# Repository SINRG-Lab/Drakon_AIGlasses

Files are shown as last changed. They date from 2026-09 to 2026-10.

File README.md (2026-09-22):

# Drakon AI Glasses

Hardware, firmware, and 3D models for the Drakon AI smart glasses.

This repository is the single home for everything physical and embedded: board
designs, embedded firmware, and printable frame parts. Application code,
measurement studies, and companion apps live in other repositories.

## Editions

The glasses come in two open-source editions that share a frame and audio
pipeline but differ in how they reach the network.

| Edition | Directory | Connectivity | Status |
|---|---|---|---|
| Companion | [`companion/`](companion/) | Wi-Fi / BLE, relayed via a paired device | v3 fabricated, v4 in design |
| Standalone | [`standalone/`](standalone/) | On-board cellular | v1 in design |

## Versions

Each edition is numbered independently — `companion/v3` and `standalone/v1` are
unrelated designs. Numbering continues each edition's own history, so the
companion boards start at v3 to match the `pcbv3` the team already builds.

| Version | Status |
|---|---|
| [`companion/v3`](companion/v3/) | **Current** — left and right boards fabricated |
| [`companion/v4`](companion/v4/) | Next — in design, empty |
| [`standalone/v1`](standalone/v1/) | First board — in design, empty |

A new version directory is created when the PCB changes in a way that breaks
compatibility with existing firmware or frame parts. Small fixes land in the
existing version. See [`docs/versioning.md`](docs/versioning.md).

## Layout

Every build is **two PCBs**, one per temple, so `hardware/` splits left/right.

```
<edition>/<version>/
├── firmware/            Embedded source for that board version
│   ├── src/  include/  lib/
├── hardware/
│   ├── left/            Left temple board
│   │   ├── kicad/       The KiCad project — .kicad_pro, .kicad_sch, .kicad_pcb
│   │   ├── fabrication/ gerbers/ and position/ files as sent to the fab
│   │   ├── bom/         Bills of materials
│   │   └── exports/     Schematic PDFs, STEP models, renders
│   ├── right/           Right temple board — same layout
│   └── shared/          Symbols, footprints and datasheets used by both
└── 3d-models/
    ├── cad/             Editable CAD source (STEP, SLDPRT, F3D)
    ├── exports/         Print-ready meshes (STL, 3MF)
    └── renders/         Images for docs and papers

common/                  Shared across editions and versions
├── firmware/  hardware/  3d-models/  scripts/

docs/
├── specs/  assembly/  bring-up/  versioning.md
```

## Conventions

- **Keep each KiCad project in one directory.** `.kicad_pro`, `.kicad_sch` and
  `.kicad_pcb` must sit together under `kicad/` or the project will not open.
- **Put a file under `common/` only once a second edition or version actually
  uses it.** Premature sharing is harder to undo than duplication.
- **Commit CAD source alongside exports.** An STL with no editable source is a
  dead end.
- **Commit fabrication outputs even though they are generated.** They are the
  exact files sent to the fab; regenerating from a newer KiCad will not
  reproduce what was actually built.
- **Never commit secrets.** Firmware credentials belong in an ignored
  `config.h` beside a committed `config.h.template`.
- **Do not commit KiCad backups, `fp-info-cache`, or `.kicad_prl`.** They are
  local caches and editor state; `.gitignore` covers them.

## Git LFS

CAD, mesh, fabrication and datasheet binaries are tracked with
[Git LFS](https://git-lfs.com) — see [`.gitattributes`](.gitattributes). Run
this once per clone, before adding any such files:

```
git lfs install
```

Note that binaries committed before LFS was configured remain ordinary blobs in
history. Converting them requires `git lfs migrate`, which rewrites history and
needs a force-push — coordinate with the team before doing it.

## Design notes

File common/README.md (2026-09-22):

# Common

Assets shared across more than one edition or revision.

- [`firmware/`](firmware/) — libraries used by more than one build
- [`hardware/`](hardware/) — KiCad symbols, footprints, and shared datasheets
- [`3d-models/`](3d-models/) — parts common to every build, e.g. the charging cradle
- [`scripts/`](scripts/) — flashing, export, and build helpers

Move something here only once a second edition or revision actually uses it.
Code that lives in `common/` is code that cannot be changed for one board
without checking every other board, so the bar for adding to it is a real
second consumer — not an anticipated one.

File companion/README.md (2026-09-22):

# Drakon — Companion Edition

The companion-linked build. The glasses handle capture, audio I/O and local
processing; network access is relayed through a paired phone or host over
Wi-Fi/BLE.

Built on a Seeed XIAO **ESP32-C6** with a MAX98357A I2S amplifier and a CUI
CMS-15116-SP speaker. Compared to the [Standalone Edition](../standalone/),
this build trades untethered operation for lower cost, lower power and a
smaller board.

| Version | Status | Notes |
|---|---|---|
| [`v3`](v3/) | **Current** | Left and right boards fabricated; KiCad sources and fab outputs in repo |
| [`v4`](v4/) | In design | Empty — scaffold only |

Numbering starts at v3 because v1 and v2 predate this repository.

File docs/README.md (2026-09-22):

# Documentation

Cross-cutting documentation. Anything specific to one board revision belongs in
that revision's own directory instead.

- [`versioning.md`](versioning.md) — edition and revision conventions
- [`specs/`](specs/) — requirements, pinouts, power budgets, mechanical drawings
- [`assembly/`](assembly/) — build and assembly instructions
- [`bring-up/`](bring-up/) — board bring-up procedures and debugging notes

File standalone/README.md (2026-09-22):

# Drakon — Standalone Edition

The untethered build. An on-board cellular modem lets the glasses reach the
network directly, with no companion device in the path.

Compared to the [Companion Edition](../companion/), this build adds the modem,
its antenna and RF front end, and a larger power budget. Prior cellular work
was done on a Walter dev board (ESP32-S3 + Sequans Monarch 2) rather than a
Drakon PCB, so no board has been fabricated for this edition yet.

| Version | Status | Notes |
|---|---|---|
| [`v1`](v1/) | In design | Empty — scaffold only |

Versions are numbered independently of the Companion Edition.

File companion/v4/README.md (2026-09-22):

# Drakon Companion Edition — v4

**Status:** In design. Nothing here is built or verified yet.

| | |
|---|---|
| Edition | Companion Edition |
| Version | `v4` |
| Connectivity | Wi-Fi / BLE via a paired device |
| SoC | _TBD_ |
| Boards | left + right temple |

## Contents

- [`firmware/`](firmware/) — embedded source for this board version
- [`hardware/`](hardware/) — KiCad projects, fabrication outputs, BOMs
- [`3d-models/`](3d-models/) — frame and enclosure CAD plus print exports

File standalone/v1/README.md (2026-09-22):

# Drakon Standalone Edition — v1

**Status:** In design. No board fabricated yet.

| | |
|---|---|
| Edition | Standalone Edition |
| Version | `v1` |
| Connectivity | On-board cellular |
| SoC | _TBD_ |
| Boards | left + right temple |

## Contents

- [`firmware/`](firmware/) — embedded source for this board version
- [`hardware/`](hardware/) — KiCad projects, fabrication outputs, BOMs
- [`3d-models/`](3d-models/) — frame and enclosure CAD plus print exports

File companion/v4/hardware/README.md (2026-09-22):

# Hardware — companion/v3

Two boards, one per temple.

- [`left/`](left/) — left temple board
- [`right/`](right/) — right temple board
- [`shared/`](shared/) — symbols, footprints and datasheets used by both

Each board directory holds:

| Directory | Contents |
|---|---|
| `kicad/` | The KiCad project. `.kicad_pro`, `.kicad_sch` and `.kicad_pcb` must stay together here or the project will not open. |
| `fabrication/` | `gerbers/` and `position/` exactly as sent to the fab |
| `bom/` | Bills of materials |
| `exports/` | Schematic PDFs, STEP models, renders |

Do not commit `*-backups/`, `fp-info-cache` or `*.kicad_prl` — they are local
caches and editor state, and `.gitignore` already covers them.

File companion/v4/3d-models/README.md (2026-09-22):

# 3D Models — companion/v3

- `cad/` — editable source (STEP, SLDPRT, F3D). Always commit this.
- `exports/` — print-ready meshes (STL, 3MF), exported from `cad/`
- `renders/` — images for documentation and papers

Name each export after its source part so the pair is obvious, and record print
settings (material, layer height, supports) here as parts are added.

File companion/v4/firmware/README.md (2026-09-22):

# Firmware — companion/v3

Embedded source targeting this board version.

- `src/` — application and driver sources
- `include/` — public headers
- `lib/` — vendored or project-local libraries

Credentials go in `src/config.h`, which is gitignored. Commit a
`src/config.h.template` with the values blanked so others know what to fill in.

Firmware releases are tagged `companion/v3/vX.Y.Z` rather than kept in separate
directories — the directory says which board, the tag says which build.

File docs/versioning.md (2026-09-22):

# Versioning

## Editions

An **edition** is a product line with its own board family. Editions live at the
top level: `companion/` and `standalone/`. A new edition is added only for a
fundamentally different product, not for a component swap.

## Versions

A **version** is a board version within an edition: `v1`, `v2`, `v3`, and so on.
Each version directory holds the firmware, hardware design, and frame parts that
belong together as one buildable unit.

Editions are numbered independently, each continuing its own history:

- `companion/` starts at **v3**, matching the `pcbv3` the team already builds.
  v1 and v2 predate this repository.
- `standalone/` starts at **v1** — no board has been fabricated yet.

`companion/v3` and `standalone/v1` are unrelated designs, and a shared number
between editions would mean nothing.

Each version is two PCBs, one per temple, under `hardware/left/` and
`hardware/right/`.

### When to create a new version

Create one when the board changes in a way that breaks compatibility with
existing firmware or frame parts:

- Pin assignments change, or a peripheral is added or removed
- The board outline changes enough that the frame no longer fits
- A component swap requires a different driver

### When not to

Fix it in place, in the existing version directory:

- Silkscreen, labelling, or documentation corrections
- Component substitutions that are drop-in compatible
- Firmware bug fixes and features on unchanged hardware

### Lifecycle

| Stage | Meaning |
|---|---|
| In design | Schematic and layout in progress; nothing fabricated |
| Prototype | Boards fabricated and in bring-up |
| Current | Validated; the version to build against |
| Superseded | A later version has taken over; kept for reference |

Record the current stage in each version's `README.md`. Version directories are
never deleted — a superseded version stays as the reference for hardware already
in the field.

Create the next version's directory when design work on it actually starts, not
in advance.

## Firmware versions

Firmware is tagged, not directory-versioned. Use
`<edition>/<version>/vX.Y.Z` — for example `companion/v3/v1.2.0`. The version
directory says which board the firmware targets; the tag says which build of
that firmware it is.

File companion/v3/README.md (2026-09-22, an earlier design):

# Drakon Companion Edition — v3

**Status:** Current — both boards fabricated.

| | |
|---|---|
| Edition | Companion Edition |
| Version | `v3` |
| Connectivity | Wi-Fi / BLE via a paired device |
| SoC | Seeed XIAO ESP32-C6 |
| Boards | left + right temple |

## Contents

- [`firmware/`](firmware/) — embedded source for this board version
- [`hardware/`](hardware/) — KiCad projects, fabrication outputs, BOMs
- [`3d-models/`](3d-models/) — frame and enclosure CAD plus print exports

## Open items

- **The right hinge board has no gerbers.** What shipped in the original upload
  as the right board's fabrication output was a second export of the left
  board. See [`hardware/right/README.md`](hardware/right/README.md).
- **The left board has two gerber exports** (1 Jun and 4 Jun 2026) and neither
  is marked as manufactured. See [`hardware/left/README.md`](hardware/left/README.md).
- BOM and position files are named `V4` on a v3 board.

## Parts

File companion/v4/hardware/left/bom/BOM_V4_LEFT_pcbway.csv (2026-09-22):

PCBWay Bom Quotation, Product No.:T-X6W1030650A
Item # | *Designator | *Qty | Manufacturer | *Mfg Part # | Description / Value | Vendor Part # | *Package/Footprint | *Unit Price(5 units) | *Total | *Delivery Time | *Actual Purchase Mfg Part # | *PCBWay Note | Customer Reply | PCBWay Update
1 | J3 | 1 | Hirose Electric Co Ltd | TF31-6S-0.5SH(800) | TF31-6S-0.5SH_800_『 』6 Position FFC, FPC Connector Contacts, Bottom 0.020 (0.50mm) Surface Mount, Right Angle | 26-TF31-6S-0.5SH(800)CT-ND | HRS_TF31-6S-0.5SH_800_ | $0.395 | $1.975
2 | D2 | 1 | Lite-On Inc. | LTST-C171KGKT | LED_G『 』Green 571nm LED Indication - Discrete 2V 0805 (2012 Metric) | 160-1426-1-ND | LED_0805_2012Metric | $0.036 | $0.180
3 | R1 | 1 | Panasonic Industry | ERA-6AEB104V | 100k『 』100 kOhms ±0.1% 0.125W, 1/8W Chip Resistor 0805 (2012 Metric) Automotive AEC-Q200 Thin Film | P100KDACT-ND | R_0805_2012Metric_Pad1.20x1.40mm_HandSolder | $0.473 | $2.365
4 | R3,R2 | 2 | Panasonic Industry | ERJ-6GEYJ512V | 5.1K『 』5.1 kOhms ±5% 0.125W, 1/8W Chip Resistor 0805 (2012 Metric) Automotive AEC-Q200 Thick Film | P5.1KACT-ND | R_0805_2012Metric | $0.069 | $0.690
5 | R5 | 1 | Panasonic Industry | ERA-6AEB4642V | 46.4k『 』46.4 kOhms ±0.1% 0.125W, 1/8W Chip Resistor 0805 (2012 Metric) Automotive AEC-Q200 Thin Film | P46.4KDACT-ND | R_0805_2012Metric | $0.473 | $2.365
6 | C5,C4 | 2 | Samsung Electro-Mechanics | CL21C221JBANNNC | 220PF『 』220 pF ±5% 50V Ceramic Capacitor C0G, NP0 0805 (2012 Metric) | 1276-1164-1-ND | C_0805_2012Metric_Pad1.18x1.45mm_HandSolder | $0.076 | $0.760
7 | FB2,FB1 | 2 | Murata Electronics | BLM21PG600SN1D | FerriteBead『 』60 Ohms @ 100 MHz 1 Power Line Ferrite Bead 0805 (2012 Metric) 3.5A 20mOhm | 490-1053-1-ND | L_0805_2012Metric_Pad1.05x1.20mm_HandSolder | $0.075 | $0.750
8 | U2 | 1 | Texas Instruments | BQ24074RGTT | BQ24074RGT『 』Charger IC Lithium Ion 16-VQFN (3x3) | 296-23798-1-ND | VQFN-16-1EP_3x3mm_P0.5mm_EP1.6x1.6mm | $2.276 | $11.380
9 | C2 | 1 | NextGen Components | CL21B104KBCNNNC | 0.1UF『 』0.1 µF ±10% 50V Ceramic Capacitor X7R 0805 (2012 Metric) | 1276-1003-1-ND | C_0805_2012Metric_Pad1.18x1.45mm_HandSolder | $0.158 | $0.790
10 | R10,R8 | 2 | Panasonic Industry | ERA-6AEB152V | 1.5K『 』1.5 kOhms ±0.1% 0.125W, 1/8W Chip Resistor 0805 (2012 Metric) Automotive AEC-Q200 Thin Film | P1.5KDACT-ND | R_0805_2012Metric | $0.284 | $2.840
11 | J1 | 1 | GCT | USB4125-GF-A | USB_C_Receptacle_PowerOnly_6P『 』USB-C (USB TYPE-C) Receptacle Connector 24 (6+18 Dummy) - Power Only 6 Pin Position Surface Mount, Right Angle; Through Hole | 2073-USB4125-GF-ACT-ND | USB_C_Receptacle_GCT_USB4125-xx-x_6P_TopMnt_Horizontal | $1.159 | $5.795
12 | U1 | 1 | Analog Devices Inc./Maxim Integrated | MAX98357AETE+T | MAX98357AETE_T『 』Amplifier IC 1-Channel (Mono) Class D 16-TQFN (3x3) | MAX98357AETE+TCT-ND | QFN50P300X300X80-17N | $1.181 | $5.905
13 | SW1 | 1 | C&K | PCM12SMTR | SW_SPDT『 』Slide Switch SPDT Surface Mount, Right Angle | 401-2016-1-ND | SW_SPDT_PCM12 | $1.328 | $6.640
14 | R7 | 1 | Panasonic Industry | ERJ-6ENF1181V | 1.18k『 』1.18 kOhms ±1% 0.125W, 1/8W Chip Resistor 0805 (2012 Metric) Automotive AEC-Q200 Thick Film | P1.18KCCT-ND | R_0805_2012Metric | $0.116 | $0.580
15 | C7,C6 | 2 | Samsung Electro-Mechanics | CL21A475KAQNNNE | 4.7uf『 』4.7 µF ±10% 25V Ceramic Capacitor X5R 0805 (2012 Metric) | 1276-1244-1-ND | C_0805_2012Metric | $0.095 | $0.950
16 | D1 | 1 | Lite-On Inc. | 160-1415-1-ND | LED_R『 』Red 631nm LED Indication - Discrete 2V 0805 (2012 Metric) | 160-1415-1-ND | LED_0805_2012Metric | $0.027 | $0.135 |  | LTST-C170KRKT
17 | R6 | 1 | Panasonic Industry | ERJ-6ENF1181V | 1.18k『 』1.18 kOhms ±1% 0.125W, 1/8W Chip Resistor 0805 (2012 Metric) Automotive AEC-Q200 Thick Film | P1.18KCCT-ND | R_0805_2012Metric | $0.116 | $0.580
18 | R4 | 1 | Panasonic Industry | ERJ-6GEYJ392V | 3.9 kOhms ±5% 0.125W, 1/8W Chip Resistor 0805 (2012 Metric) Automotive AEC-Q200 Thick Film | P3.9KACT-ND | R_0805_2012Metric
19 | R9 | 1 | Panasonic Industry | ERJ-6ENF1002V | 10k『 』10 kOhms ±1% 0.125W, 1/8W Chip Resistor 0805 (2012 Metric) Automotive AEC-Q200 Thick Film | P10.0KCCT-ND | R_0805_2012Metric | $0.116 | $0.580
20 | C3 | 1 | Samsung Electro-Mechanics | CL21A106KOQNNNE | 10UF『 』10 µF ±10% 16V Ceramic Capacitor X5R 0805 (2012 Metric) | 1276-1096-1-ND | C_0805_2012Metric_Pad1.18x1.45mm_HandSolder | $0.158 | $0.790
21 | C1 | 1 | Samsung Electro-Mechanics | CL21B104KBCNNNC | 1UF『 』0.1 µF ±10% 50V Ceramic Capacitor X7R 0805 (2012 Metric) | 1276-1003-1-ND | C_0805_2012Metric | $0.158 | $0.790
 |  |  |  |  |  |  |  | Component Cost | $46.84

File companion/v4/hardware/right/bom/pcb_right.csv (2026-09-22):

Id | Designator | Footprint | Quantity | Designation | Supplier and ref
1 | C3 | C_0805_2012Metric_Pad1.18x1.45mm_HandSolder | 1 | 0.1UF
2 | U2 | QFN50P300X300X80-17N | 1 | MAX98357AETE_T
3 | FB1,FB2 | L_0805_2012Metric_Pad1.05x1.20mm_HandSolder | 2 | FerriteBead
4 | R3,R2 | R_0805_2012Metric_Pad1.20x1.40mm_HandSolder | 2 | 100k
5 | U1 | MODULE_113991254 | 1 | 113991254
6 | C2,C1 | C_0805_2012Metric_Pad1.18x1.45mm_HandSolder | 2 | 220PF
7 | J1 | HRS_TF31-6S-0.5SH_800_ | 1 | TF31-6S-0.5SH_800_
8 | C4 | C_0805_2012Metric_Pad1.18x1.45mm_HandSolder | 1 | 10UF
9 | SW1 | SW_PUSH_6mm_H5mm | 1 | SW_Push
10 | R1 | R_0805_2012Metric_Pad1.20x1.40mm_HandSolder | 1 | 47k
11 | J2 | PinHeader_1x02_P2.54mm_Vertical | 1 | speaker

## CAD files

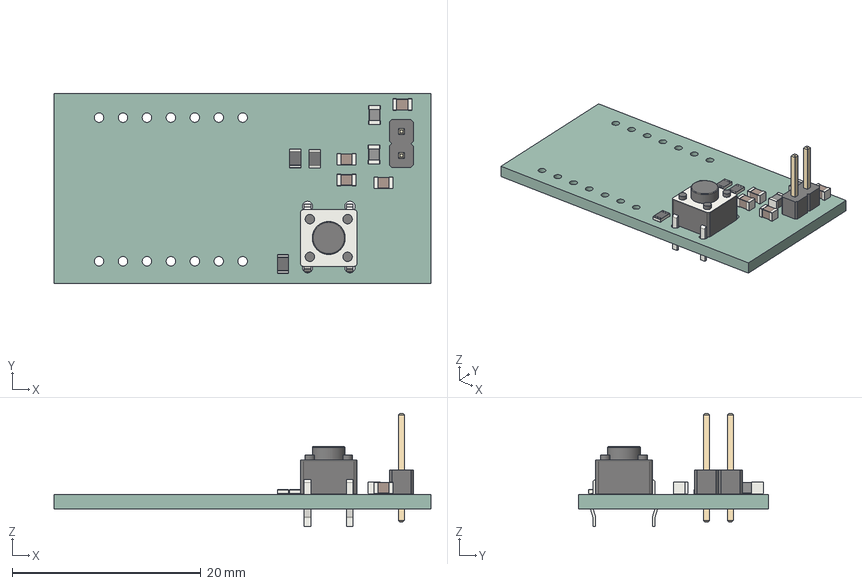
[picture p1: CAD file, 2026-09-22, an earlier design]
companion/v3/hardware/right/exports/pcb_right.step
40.0 x 20.2 x 12.0 mm
C_0805_2012Metric x 4
L_0805_2012Metric x 2
R_0805_2012Metric x 3
SW_PUSH_6mm_H5mm
PinHeader_1x02_P2.54mm_Vertical
pcb_right_PCB

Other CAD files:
companion/v4/hardware/right/exports/pcb_right.step
companion/v4/hardware/shared/symbols/CMS-15116-SP/CMS-15116-SP.step
companion/v4/hardware/shared/symbols/MAX98357AETE_T/MAX98357AETE_T.step

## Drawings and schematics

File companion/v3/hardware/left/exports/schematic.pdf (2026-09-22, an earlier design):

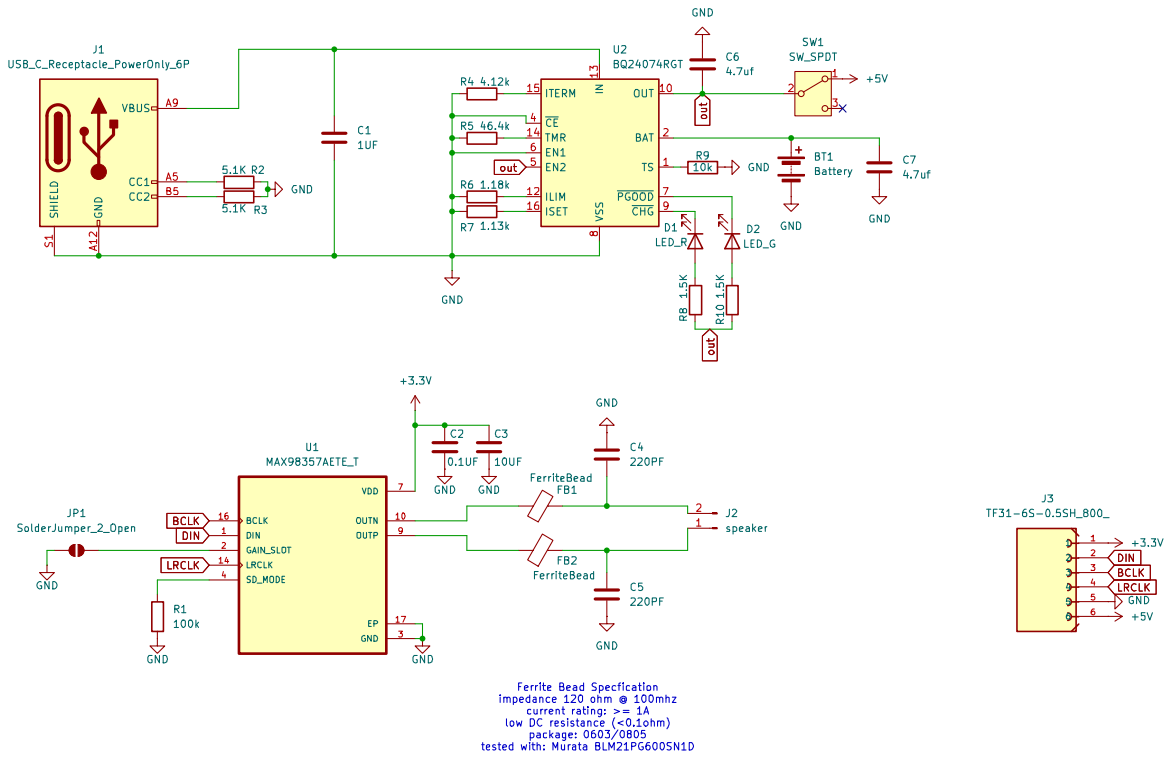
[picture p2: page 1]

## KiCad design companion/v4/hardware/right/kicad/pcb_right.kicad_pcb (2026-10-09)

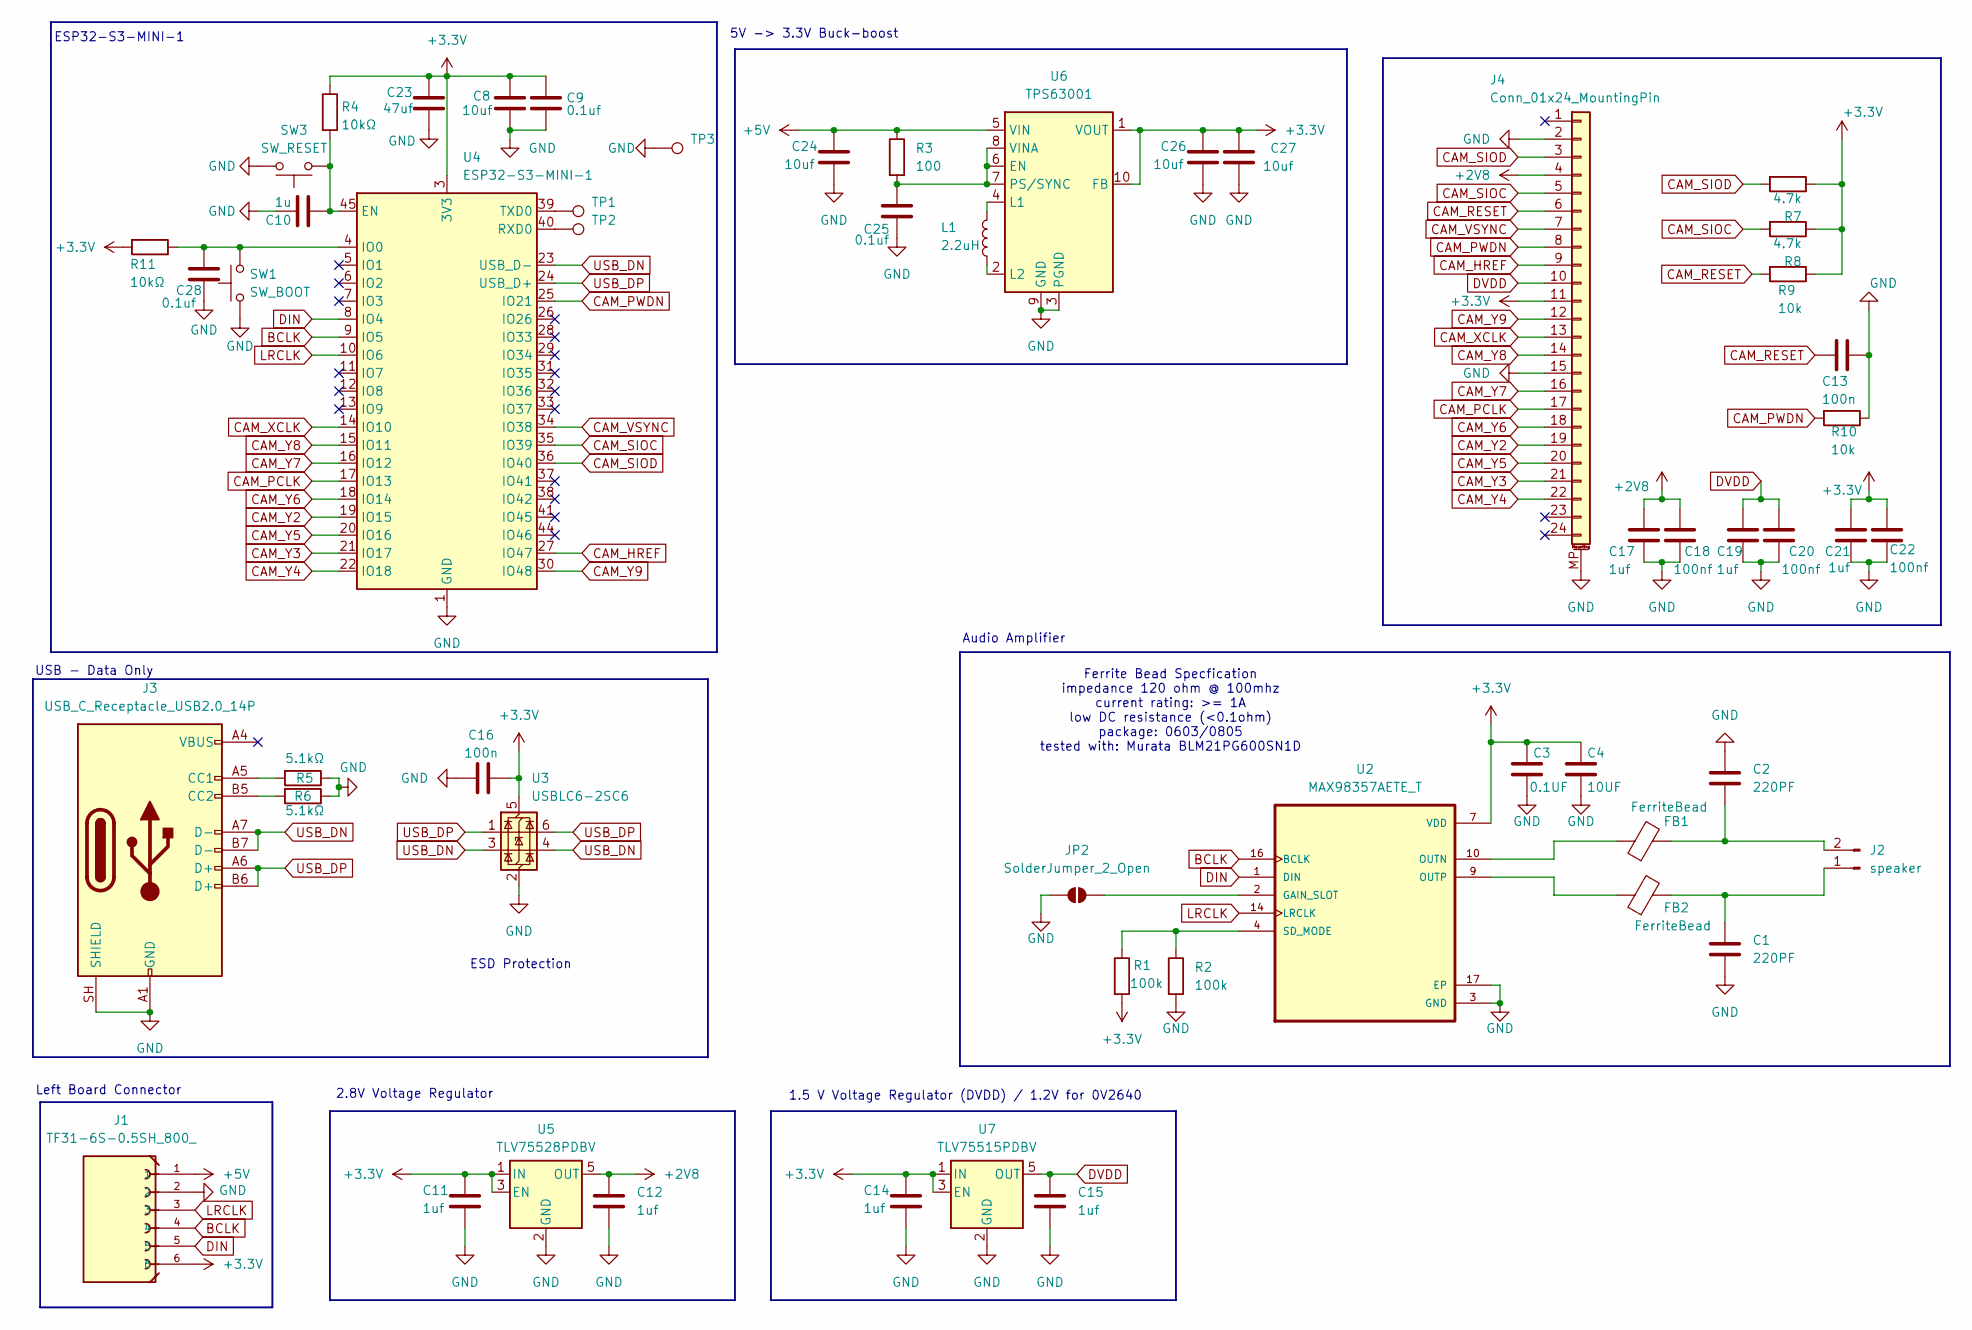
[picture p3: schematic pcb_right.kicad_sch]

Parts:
C1, C2: 220PF; C_0805_2012Metric_Pad1.18x1.45mm_HandSolder
C3: 0.1UF; C_0805_2012Metric_Pad1.18x1.45mm_HandSolder
C4: 10UF; C_0805_2012Metric_Pad1.18x1.45mm_HandSolder
C8, C24, C26, C27: 10uf; C_0402_1005Metric
C9, C25, C28: 0.1uf; C_0402_1005Metric
C10: 1u; C_0402_1005Metric
C11, C12, C14, C15, C17, C19, C21: 1uf; C_0402_1005Metric
C13, C16: 100n; C_0402_1005Metric
C18, C20, C22: 100nf; C_0402_1005Metric
C23: 47uf; C_0402_1005Metric
FB1, FB2: FerriteBead; L_0805_2012Metric_Pad1.05x1.20mm_HandSolder
J1: TF31-6S-0.5SH_800_; HRS_TF31-6S-0.5SH_800_
J2: speaker; PinHeader_1x02_P2.54mm_Vertical
J3: USB_C_Receptacle_USB2.0_14P; USB_C_Receptacle_HRO_TYPE-C-31-M-12
J4: Conn_01x24_MountingPin; Hirose_FH12-24S-0.5SH_1x24-1MP_P0.50mm_Horizontal
JP2: SolderJumper_2_Open; SolderJumper-2_P1.3mm_Open_RoundedPad1.0x1.5mm
L1: 2.2uH; Texas_DRC0010J_ThermalVias
R1, R2: 100k; R_0805_2012Metric_Pad1.20x1.40mm_HandSolder
R3: 100; R_0805_2012Metric_Pad1.20x1.40mm_HandSolder
R4, R11: 10kΩ; R_0402_1005Metric
R5, R6: 5.1kΩ; R_0402_1005Metric
R7, R8: 4.7k; R_0805_2012Metric_Pad1.20x1.40mm_HandSolder
R9, R10: 10k; R_0805_2012Metric_Pad1.20x1.40mm_HandSolder
SW1: SW_BOOT; SW_PUSH_6mm_H5mm
SW3: SW_RESET; SW_PUSH_6mm_H5mm
TP1: TX; SOT-23-5
TP2: RX; TestPoint_Pad_D1.5mm
TP3: GND; TestPoint_Pad_D1.5mm
U2: MAX98357AETE_T; QFN50P300X300X80-17N
U3: USBLC6-2SC6; SOT-23-6
U4: ESP32-S3-MINI-1; ESP32-S2-MINI-1
U5: TLV75528PDBV; SOT-23-5
U6: TPS63001; Texas_DRC0010J_ThermalVias
U7: TLV75515PDBV; SOT-23-5

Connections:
+2V8: C12.1, C17.1, C18.1, J4.4, U5.5 (OUT)
+3.3V: C3.1, C4.1, C8.1, C9.1, C11.1, C14.1, C16.2, C21.1, C22.1, C23.1, C26.1, C27.1, J1.6, J4.11, R1.2, R4.1, R7.1, R8.1, R9.1, R11.2, U2.7 (VDD), U2.8 (VDD), U3.5 (VBUS), U4.3 (3V3), U5.1 (IN), U5.3 (EN), U6.1 (VOUT), U6.10 (FB), U7.1 (IN), U7.3 (EN)
+5V: C24.1, J1.1, R3.1, U6.5 (VIN)
BCLK: J1.4, U2.16 (BCLK), U4.9 (IO5)
CAM_HREF: J4.9, U4.27 (IO47)
CAM_PCLK: J4.17, U4.17 (IO13)
CAM_PWDN: J4.8, R10.2, U4.25 (IO21)
CAM_RESET: C13.2, J4.6, R9.2
CAM_SIOC: J4.5, R8.2, U4.35 (IO39)
CAM_SIOD: J4.3, R7.2, U4.36 (IO40)
CAM_VSYNC: J4.7, U4.34 (IO38)
CAM_XCLK: J4.13, U4.14 (IO10)
CAM_Y2: J4.19, U4.19 (IO15)
CAM_Y3: J4.21, U4.21 (IO17)
CAM_Y4: J4.22, U4.22 (IO18)
CAM_Y5: J4.20, U4.20 (IO16)
CAM_Y6: J4.18, U4.18 (IO14)
CAM_Y7: J4.16, U4.16 (IO12)
CAM_Y8: J4.14, U4.15 (IO11)
CAM_Y9: J4.12, U4.30 (IO48)
DIN: J1.5, U2.1 (DIN), U4.8 (IO4)
DVDD: C15.1, C19.1, C20.1, J4.10, U7.5 (OUT)
GND: C1.2, C2.1, C3.2, C4.2, C8.2, C9.2, C10.2, C11.2, C12.2, C13.1, C14.2, C15.2, C16.1, C17.2, C18.2, C19.2, C20.2, C21.2, C22.2, C23.2, C24.2, C25.2, C26.2, C27.2, C28.2, J1.2, J3.A1 (GND), J3.A12 (GND), J3.B1 (GND), J3.B12 (GND), J3.SH (SHIELD), J4.2, J4.15, J4.MP (MountPin), JP2.1 (A), R2.2, R5.1, R6.1, R10.1, SW1.1, SW3.2, TP3.1 (1_1), U2.3 (GND), U2.11 (GND), U2.15 (GND), U2.17 (EP), U3.2 (GND), U4.1 (GND), U4.2 (GND), U4.42 (GND), U4.43 (GND), U4.46 (GND), U4.47 (GND), U4.48 (GND), U4.49 (GND), U4.50 (GND), U4.51 (GND), U4.52 (GND), U4.53 (GND), U4.54 (GND), U4.55 (GND), U4.56 (GND), U4.57 (GND), U4.58 (GND), U4.59 (GND), U4.60 (GND), U4.61 (GND), U4.62 (GND), U4.63 (GND), U4.64 (GND), U4.65 (GND), U5.2 (GND), U6.3 (PGND), U6.9 (GND), U6.11 (PGND), U7.2 (GND)
LRCLK: J1.3, U2.14 (LRCLK), U4.10 (IO6)
unnamed: C1.1, FB2.2, J2.1
unnamed: C2.2, FB1.2, J2.2
unnamed: J3.A5 (CC1), R5.2
unnamed: J3.B5 (CC2), R6.2
unnamed: JP2.2 (B), U2.2 (GAIN_SLOT)
unnamed: FB1.1, U2.10 (OUTN)
unnamed: FB2.1, U2.9 (OUTP)
unnamed: R1.1, R2.1, U2.4 (SD_MODE)
unnamed: C10.1, R4.2, SW3.1, U4.45 (EN)
unnamed: C28.1, R11.1, SW1.2, U4.4 (IO0)
unnamed: TP2.1 (1_1), U4.40 (RXD0)
unnamed: TP1.1 (1_1), U4.39 (TXD0)
unnamed: C25.1, R3.2, U6.6 (EN), U6.7 (PS/SYNC), U6.8 (VINA)
unnamed: L1.2, U6.4 (L1)
unnamed: L1.1, U6.2 (L2)
USB_DN: J3.A7 (D-), J3.B7 (D-), U3.3 (I/O2), U3.4 (I/O2), U4.23 (USB_D-)
USB_DP: J3.A6 (D+), J3.B6 (D+), U3.1 (I/O1), U3.6 (I/O1), U4.24 (USB_D+)

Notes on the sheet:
1.5 V Voltage Regulator (DVDD) / 1.2V for 0V2640
USB - Data Only
ESP32-S3-MINI-1
Left Board Connector
Audio Amplifier
2.8V Voltage Regulator
5V -> 3.3V Buck-boost
ESD Protection
Ferrite Bead Specfication impedance 120 ohm @ 100mhz current rating: >= 1A low DC resistance (<0.1ohm) package: 0603/0805 tested with: Murata BLM21PG600SN1D

Board: 2 copper layers, 55 parts (0 on the bottom side), 41 nets, no tracks yet.

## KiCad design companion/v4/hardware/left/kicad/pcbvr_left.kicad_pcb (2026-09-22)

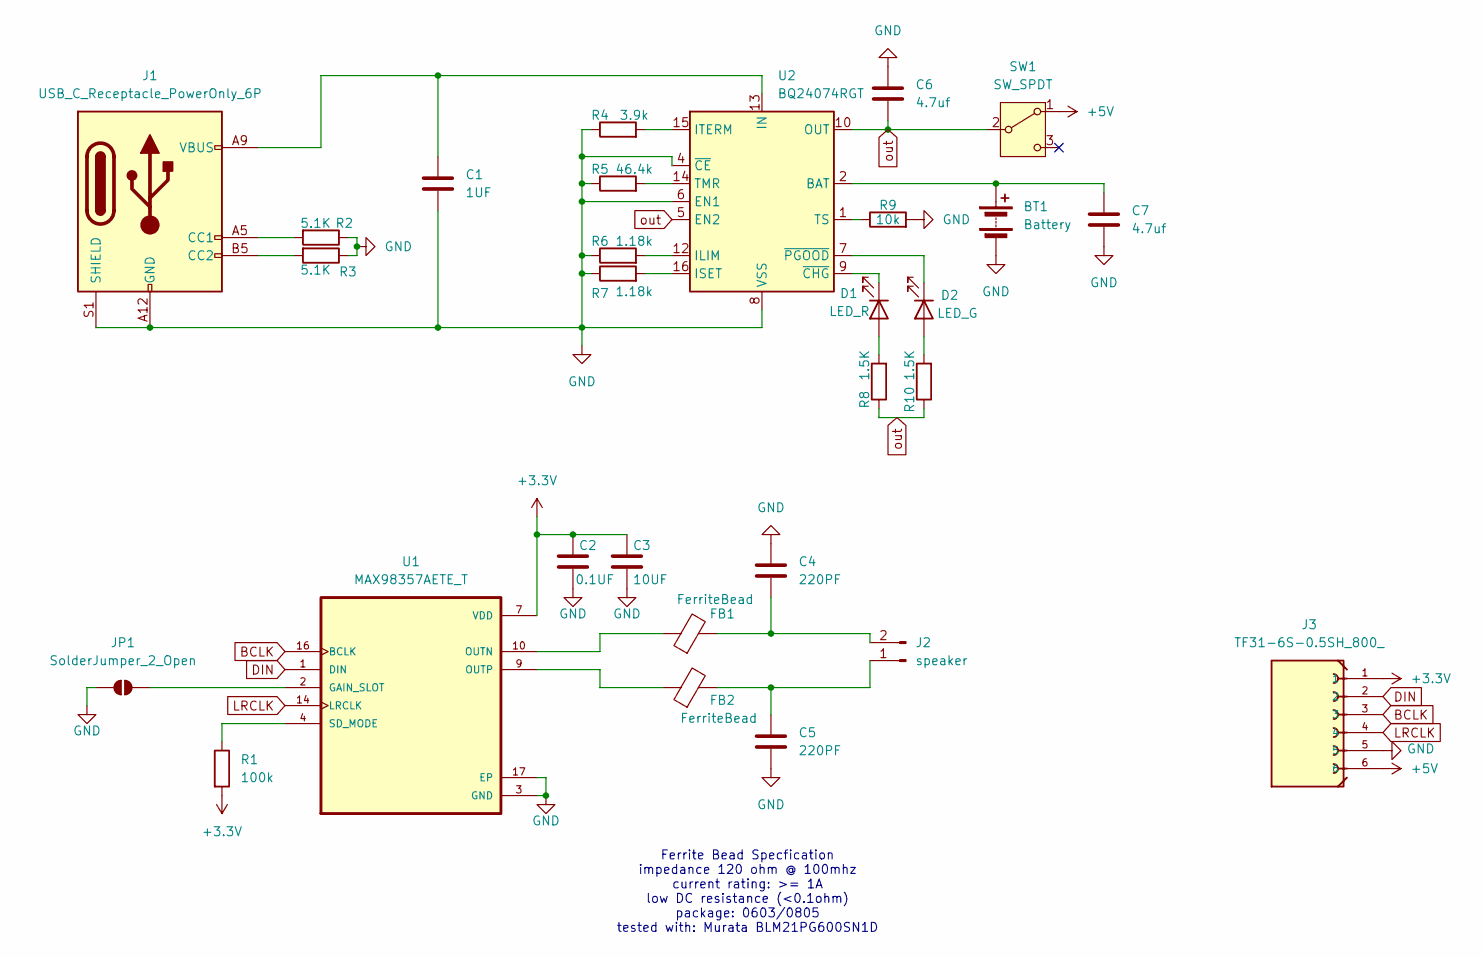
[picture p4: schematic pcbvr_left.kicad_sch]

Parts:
BT1: Battery; JST_PH_S2B-PH-K_1x02_P2.00mm_Horizontal
C1: 1UF; C_0805_2012Metric
C2: 0.1UF; C_0805_2012Metric_Pad1.18x1.45mm_HandSolder
C3: 10UF; C_0805_2012Metric_Pad1.18x1.45mm_HandSolder
C4, C5: 220PF; C_0805_2012Metric_Pad1.18x1.45mm_HandSolder
C6, C7: 4.7uf; C_0805_2012Metric
D1: LED_R; LED_0805_2012Metric
D2: LED_G; LED_0805_2012Metric
FB1, FB2: FerriteBead; L_0805_2012Metric_Pad1.05x1.20mm_HandSolder
J1: USB_C_Receptacle_PowerOnly_6P; USB_C_Receptacle_GCT_USB4125-xx-x_6P_TopMnt_Horizontal
J2: speaker; PinHeader_1x02_P2.54mm_Vertical
J3: TF31-6S-0.5SH_800_; HRS_TF31-6S-0.5SH_800_
JP1: SolderJumper_2_Open; SolderJumper-2_P1.3mm_Open_RoundedPad1.0x1.5mm
R1: 100k; R_0805_2012Metric_Pad1.20x1.40mm_HandSolder
R2, R3: 5.1K; R_0805_2012Metric
R4: 3.9k; R_0805_2012Metric
R5: 46.4k; R_0805_2012Metric
R6, R7: 1.18k; R_0805_2012Metric
R8, R10: 1.5K; R_0805_2012Metric
R9: 10k; R_0805_2012Metric
SW1: SW_SPDT; SW_SPDT_PCM12
U1: MAX98357AETE_T; QFN50P300X300X80-17N
U2: BQ24074RGT; VQFN-16-1EP_3x3mm_P0.5mm_EP1.6x1.6mm

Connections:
+3.3V: C2.1, C3.1, J3.1, R1.2, U1.7 (VDD), U1.8 (VDD)
+5V: J3.6, SW1.1 (A)
BCLK: J3.3, U1.16 (BCLK)
DIN: J3.2, U1.1 (DIN)
GND: BT1.2 (-), C1.2, C2.2, C3.2, C4.1, C5.2, C6.1, C7.2, J1.A12 (GND), J1.B12 (GND), J1.S1 (SHIELD), J3.5, JP1.1 (A), R2.1, R3.1, R4.1, R5.1, R6.1, R7.1, R9.2, U1.3 (GND), U1.11 (GND), U1.15 (GND), U1.17 (EP), U2.4 (~CE), U2.6 (EN1), U2.8 (VSS), U2.17 (VSS)
LRCLK: J3.4, U1.14 (LRCLK)
unnamed: BT1.1 (+), C7.1, U2.2 (BAT), U2.3 (BAT)
unnamed: D1.2 (A), R8.2
unnamed: D1.1 (K), U2.9 (~CHG)
unnamed: D2.2 (A), R10.2
unnamed: D2.1 (K), U2.7 (~PGOOD)
unnamed: J1.A5 (CC1), R2.2
unnamed: J1.B5 (CC2), R3.2
unnamed: C5.1, FB2.2, J2.1
unnamed: C4.2, FB1.2, J2.2
unnamed: JP1.2 (B), U1.2 (GAIN_SLOT)
unnamed: FB1.1, U1.10 (OUTN)
unnamed: FB2.1, U1.9 (OUTP)
unnamed: R1.1, U1.4 (SD_MODE)
unnamed: R6.2, U2.12 (ILIM)
unnamed: C1.1, J1.A9 (VBUS), J1.B9 (VBUS), U2.13 (IN)
unnamed: R7.2, U2.16 (ISET)
unnamed: R4.2, U2.15 (ITERM)
unnamed: R5.2, U2.14 (TMR)
unnamed: R9.1, U2.1 (TS)
out: C6.2, R8.1, R10.1, SW1.2 (B), U2.5 (EN2), U2.10 (OUT), U2.11 (OUT)

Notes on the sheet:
Ferrite Bead Specfication impedance 120 ohm @ 100mhz current rating: >= 1A low DC resistance (<0.1ohm) package: 0603/0805 tested with: Murata BLM21PG600SN1D

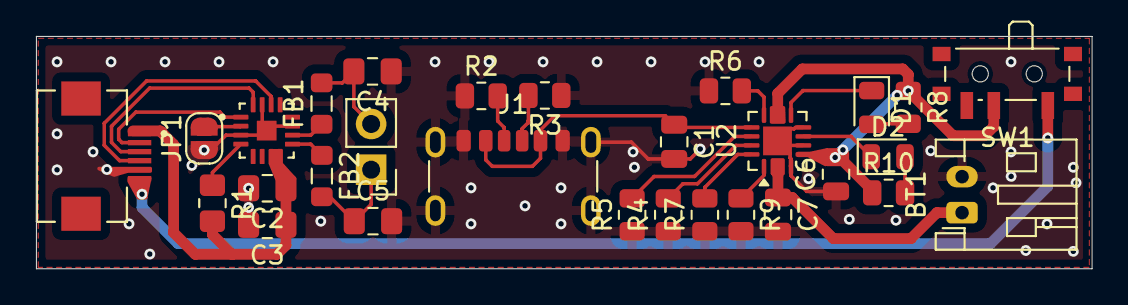
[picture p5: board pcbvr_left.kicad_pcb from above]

Board: 2 copper layers, 58.6 x 12.9 mm, 29 parts (0 on the bottom side), 26 nets.

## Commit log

2026-09-22 included pcbv3 PCB files
    [BOM_V4_LEFT_pcbway.csv, BOM_V4_RIGHT.csv, CMS-15116-SP.step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]
2026-09-22 Restructure repo by edition and version, migrate pcbv3
    Make this the home for the glasses' hardware, firmware and 3D models,
    organised so each buildable board version is self-contained.
    Two editions at the top level: companion/ (Seeed XIAO ESP32-C6, Wi-Fi/BLE via
    a paired device) and standalone/ (on-board cellular, not yet built). Each is
    numbered on its own history, so companion starts at v3 to match the pcbv3 the
    team already builds. Every version holds firmware/, hardware/ and 3d-models/,
    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
    [BOM_V4_LEFT_pcbway.csv, BOM_V4_RIGHT.csv, CMS-15116-SP.step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]
2026-09-29 Add v4 left/right hardware, began implementations for esp32-c6-mini module, included +3.3V LDO
    [BOM_V4_LEFT_pcbway.csv, BOM_V4_RIGHT.csv, CMS-15116-SP.step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]
2026-10-02 Add EN circuit, BOOT button, USB-C programming, decoupling
2026-10-02 box organiziers
    [pcb_right.kicad_sch]
2026-10-07 Camera connector
    [pcb_right.kicad_sch]
2026-10-07 rev 2 - mcu changes and other various fixes
    [pcb_right.kicad_pcb, pcb_right.kicad_sch, pcbvr_left.kicad_sch]
2026-10-09 addded component footprints
    [pcb_right.kicad_pcb, pcb_right.kicad_sch]
2026-10-09 started layout
    [pcb_right.kicad_pcb]
2026-10-26 Complete right PCB rev 1 layout and BOM
    Finish rev 1 layout for the v4 right board, add fabrication outputs
    (BOM, positions, netlist, gerbers), shared Master_lib symbols and
    footprints, 3D models, and PCB renders.
2026-11-02 Right PCB rev 2 layout and production files
    Update v4 right board layout to rev 2, add Rev2 fabrication outputs
    (BOM, positions, designators, gerbers), move rev 1 outputs into
    Rev1_Production, and add rev 2 render and Blender model.
